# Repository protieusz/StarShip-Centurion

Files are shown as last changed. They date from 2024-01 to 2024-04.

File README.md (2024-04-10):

# StarShip-Centurion
SS Centurion a 39 keys, col staggered, 34 or 25 mm trackball keyboard

Thank you PCBWay for sponsoring my wonderful StarShip Centurion design which tooks me forever to get it right. PCBWay is your one stop PCB prototype service. Their PCBA service is top notch. Whenever you are thinking of prototype your brilliant keyboard pcbs, PCBWay is your answer.

This keyboard is inspired from Le-Chiffre and Orbital.  I never had the chance to print the Le-Chiffre pcb and always wanted one but with more features like a trackball integrated to it. The SS Centurion has more pinky stagger than the Le-Chiffre or the Orbital. The trackball location is located at the thumb area in order to make the keyboard more smaller profile and more compact. The trackball PMW3360 sensor VIK module is attached by hot glue or acrylic glue to the 3DP trackball holder from the bottom.  [PMW3360-XS VIK module](https://github.com/sadekbaroudi/vik/tree/master/pcb/pmw3360-xs) is designed by Sadek of Fingerpunch and the 3DP trackball holder is designed by @ma_po_daisuki and his designs are being sold at [his Booth store](https://ma-po.booth.pm/items/5258743) which cost around $10 cad. Go check it out and support him. The height of the trackball is adjusted using M2 standoffs and connected to the keyboard pcb by a ribbon cable to the VIK trackball module. This keyboard pcb is not VIK certified since I removed a couple of the pin connections in order to save myself the headache of routing those pin connections.  The SS Centurion also have 20 RGB lights along the cut out "slots" of the case to make it look more like a starship. No encoder was added because the QMK code allows scroll lock for the trackball and I find the scroll lock is more used than the encoder itself and save some space to make the keyboard look more compact.  The build of the SS Centurion requires a lot of DIY fixes so be warned if you decided to print is out and build your own.  It is not perfect and don't expect it to be perfect.  Print at your own risk and no support will be given. Also the 3DP trackball module screw holes are edited from the original in order to accomodate the M2 hot inserts.  There are lots of workarounds for this build.  I discovered them during building but the issues were fixed and is working.

# SS Centurion Keyboard Mat
Collaborated with Philip Lalonde (https://github.com/lalondeph/StarShip-Centurion-deskpad) to help design a keymat using SS Centurion's pcb outline and design it so that it has a FTL spaceship look.  Go check out his other keymat works as well. This guy is very talented.  The SS Centurion keymat is free for you guys to print at any shops that does custom keymat printing.  I get mine printed at [Aliexpress shop](https://www.aliexpress.com/item/1005006217695445.html?spm=a2g0o.order_list.order_list_main.22.609b1802RaJOJM). Below are some keymat pictures:





# QMK Firmware
For QMK firmware, use the Ploopy version since it has been tested and works smoothly. The code is less complicated compared to Aki27 Bally's.  I have uploaded the Aki27 but I have not tested it. It does compiles with no issue. Test at your own risk.

# Quick Video Demo Use:

https://www.instagram.com/reel/C1-lobTvvmZ/?igsh=d3Zudndwd214cmZk

# Quick RGB Demo Video:

https://youtu.be/h3FHeYk4HRs

# Final Production Pictures Jan 10, 2024:







RGB Lights - I used Costco parchment paper and glued it inside the case for the RGB slits to give it a warmer look or else super sharp and bright for the eyes.



























Trackball Setup. Janky but works.











Workaround for miscalculated USB C port opening:




Sadek VIK XS Trackball Module PCB Required:
Recommend SMD hot plate soldering. Manual hand soldering might cause you to rage quit.





For the SS Centurior build, orientate the PIN 1 to the bottom right corner. So the VIK connector will be on the other side. Another oversight. Unless you can manipulate the QMK code to have it rotate like the pic then kudos to you:



Test Fitting the Sadek's VIK XS pcb to the base of ma_po_daisuki trackball support holder





Hot Inserts DIY Fix. Insert Halfway to the side.





Switch Plate:




Pre-production Pics:

Top Case







PCB Renders

Screenshot 2023-12-02 at 3 38 40 PM
Screenshot 2023-12-02 at 3 39 11 PM
Screenshot 2023-12-02 at 3 39 32 PM


Fusion360 Renders

Screenshot 2023-11-30 at 2 51 08 AM
Screenshot 2023-11-30 at 2 46 51 AM
Screenshot 2023-11-30 at 2 46 30 AM
Screenshot 2023-11-30 at 2 46 14 AM
Screenshot 2023-11-30 at 2 46 03 AM
Screenshot 2023-11-30 at 2 45 52 AM
Screenshot 2023-11-30 at 2 44 59 AM
Screenshot 2023-11-30 at 2 45 37 AM
Screenshot 2023-11-30 at 2 43 17 AM

Mock Keycap Height Vs Trackball Reference

Screenshot 2023-11-30 at 1 59 52 AM
Screenshot 2023-11-30 at 1 57 09 AM
Screenshot 2023-11-30 at 1 56 57 AM

Pre-Chamfre Case

Screenshot_2023-11-29_at_7 44 43_PM
Screenshot_2023-11-29_at_7 44 51_PM
Screenshot_2023-11-29_at_7 44 43_PM

Sketch

Screenshot 2023-11-28 at 8 11 51 PM

KLE Mock Up

Screenshot_2023-11-28_at_12 25 36_PM

Physical Prototype Test



# License

</a></p>

You are free to:

Share — copy and redistribute the material in any medium or format

Adapt — remix, transform, and build upon the material

The licensor cannot revoke these freedoms as long as you follow the license terms.
Under the following terms:

Attribution — You must give appropriate credit, provide a link to the license, and indicate if changes were made. You may do so in any reasonable manner, but not in any way that suggests the licensor endorses you or your use.

NonCommercial — You may not use the material for commercial purposes.

ShareAlike — If you remix, transform, or build upon the material, you must distribute your contributions under the same license as the original.

No additional restrictions — You may not apply legal terms or technological measures that legally restrict others from doing anything the license permits.

StarShip Centurion by ProtieusKeebs is licensed under [CC BY-NC-SA 4.0](https://creativecommons.org/licenses/by-nc-sa/4.0/?ref=chooser-v1)

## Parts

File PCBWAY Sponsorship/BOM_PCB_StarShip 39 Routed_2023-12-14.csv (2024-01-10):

ID | Name | Designator | Footprint | Quantity | Manufacturer Part | Manufacturer | Supplier | Supplier Part | Price | link
1 | NO | GND,+3V3,CS,MISO,MOSI,SCK,+5V | PIN 1-PIN | 7
2 | TYPE-C-31-M-12 | USBC1 | USB-C_SMD-TYPE-C-31-M-12 | 1 | TYPE-C-31-M-12 | 韩国韩荣 | LCSC | C165948 | 0.159 | https://so.szlcsc.com/global.html?c=&k=C165948
3 | SK6812MINI-E_C5149201 | U13,U14,U15,U17,U25,U16,U18,U19,U20,U21,U22,U23,U24,U26,U27,U28,U29,U30,U31,U32 | LED-SMD_L3.2-W2.8-TR | 20 | SK6812MINI-E | 欧思科光电 | LCSC | C5149201 | 0.124 | https://lcsc.com/eda_search?q=C5149201&%26type=1&ref=editor
4 | SM4007PL | D205,D000,D001,D002,D003,D004,D005,D006,D007,D008,D009,D010,D105,D106,D107,D108,D109,D110,D206,D207,D208,D209,D210,D306,D307,D308,D100,D101,D102,D103,D104,D200,D201,D202,D203,D204,D302,D303,D304 | SOD-123F_L2.8-W1.8-LS3.7-RD | 39 | SM4007PL | MDD | LCSC | C64898 | 0.007 | https://item.szlcsc.com/60254.html
5 | 1uF | C1,C2,C5,C6,C9 | C0402 | 5 | CL05A105KA5NQNC | SAMSUNG(三星) | LCSC | C52923 | 0.004 | https://item.szlcsc.com/15869.html
6 | 22pF | C3,C4 | C0402 | 2 | 0402CG220J500NT | FH(风华) | LCSC | C1555 | 0.001 | https://item.szlcsc.com/15869.html
7 | 100nF | C7,C10,C11,C12,C13,C14,C15,C16 | C0402 | 8 | CL05B104KO5NNNC | SAMSUNG(三星) | LCSC | C1525 | 0.001 | https://item.szlcsc.com/15869.html
8 | 10uF | C8 | C0402 | 1 | CL05A106MQ5NUNC | SAMSUNG(三星) | LCSC | C15525 | 0.005 | https://item.szlcsc.com/15869.html
9 | PRTR5V0U2X,215 | D11 | SOT-143_L2.9-W1.3-P1.92-LS2.3-BR | 1 | PRTR5V0U2X,215 | Nexperia(安世) | LCSC | C12333 | 0.147 | https://item.szlcsc.com/280548.html
10 | BSMD0805-020-15V | F1 | F0805 | 1 | BSMD0805-020-15V | BHFUSE(佰宏) | LCSC | C883103 | 0.045 | https://item.szlcsc.com/343298.html
11 | FH12-12S-0.5SH(55) | FPC1 | FPC-SMD_FH12-12S-0.5SH-55 | 1 | FH12-12S-0.5SH(55) | HRS(广濑) | LCSC | C88360 | 0.428 | https://lcsc.com/eda_search?q=C88360&%26type=1&ref=editor
12 | 5.1kΩ | R1,R2,R3,R4,R5 | R0402 | 5 | 0402WGF5101TCE | UNI-ROYAL(厚声) | LCSC | C25905 | 0.001 | https://item.szlcsc.com/323315.html
13 | 1kΩ | R6,R7 | R0402 | 2 | 0402WGF1001TCE | UNI-ROYAL(厚声) | LCSC | C11702 | 0.001 | https://item.szlcsc.com/323315.html
14 | 27Ω | R8,R9 | R0402 | 2 | 0402WGF270JTCE | UNI-ROYAL(厚声) | LCSC | C25100 | 0.001 | https://item.szlcsc.com/323315.html
15 | RESET | U1 | RESET SWITCH | 1
16 | BOOT | U2 | RESET SWITCH | 1
17 | W25Q128JVSIQTR | U3 | SOIC-8_L5.3-W5.3-P1.27-LS8.0-BL | 1 | W25Q128JVSIQ | WINBOND(华邦) | LCSC | C97521 | 0.611 | https://item.szlcsc.com/63461.html
18 | RP2040 | U4 | LQFN-56_L7.0-W7.0-P0.4-EP | 1 | RP2040 | Raspberry Pi(树莓派) | LCSC | C2040 | 1.076 | https://atta.szlcsc.com/upload/public/pdf/source/20210621/C2040_96F425825606B7957D87DD32E2512CA9.pdf
19 | XC6206P332MR | U5 | SOT-23-3_L2.9-W1.6-P1.90-LS2.8-BR | 1 | XC6206P332MR | TOREX(特瑞仕) | LCSC | C5446 | 0.106 | https://item.szlcsc.com/14454.html
20 | SN74LVC1T45QDCKRQ1 | U6 | SC-70-6_L2.0-W1.3-P0.65-LS2.1-BR | 1 | SN74LVC1T45QDCKRQ1 | TI(德州仪器) | LCSC | C139353 | 0.382 | https://lcsc.com/eda_search?q=C139353&%26type=1&ref=editor
21 | 12MHz | X1 | OSC-SMD_4P-L3.2-W2.5-BL | 1 | X322512MSB4SI | YXC(扬兴晶振) | LCSC | C9002 | 0.059 | https://item.szlcsc.com/15866.html
22 | Switch | K205,K000,K001,K002,K003,K004,K005,K006,K007,K008,K009,K010,K105,K106,K107,K108,K109,K110,K206,K207,K208,K209,K210,K306,K307,K308,K100,K101,K102,K103,K104,K200,K201,K202,K203,K204,K302,K303,K304 | CHERRY_MX_100_MILLMAX | 39

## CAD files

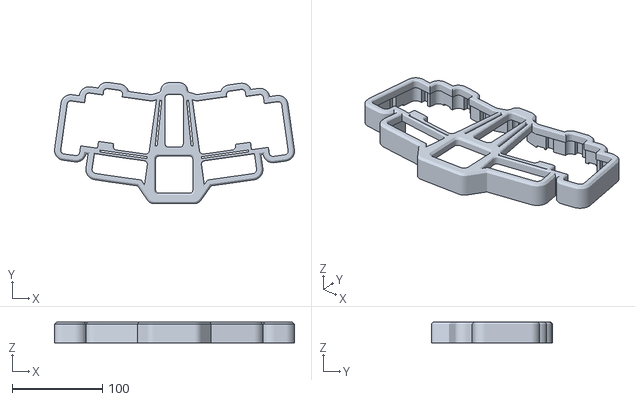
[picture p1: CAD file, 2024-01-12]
SS39TopCaseFixedUSBCPort.stl
265.6 x 134.2 x 22.8

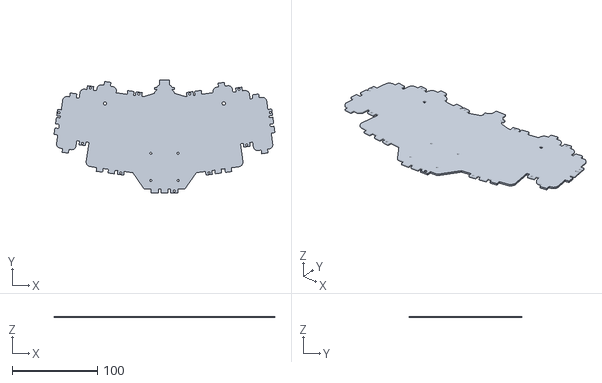
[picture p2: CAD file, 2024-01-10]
SS39BottomPlateOffsets.stl
259.1 x 132.3 x 1.60

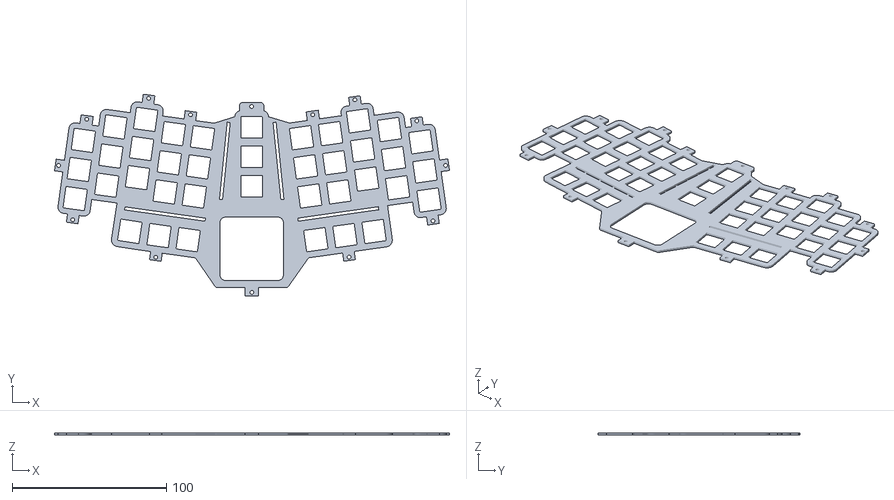
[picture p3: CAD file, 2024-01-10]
SS39SwitchPlate.stl
255.9 x 130.6 x 1.50

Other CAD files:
STEP/StarShip Centurion Top.step
STEP/StarShip Centurion Bottom.step
STEP/StarShip Centurion Switchplate.step

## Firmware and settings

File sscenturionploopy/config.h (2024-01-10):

/* Copyright 2023 Colin Lam (Ploopy Corporation)
 * Copyright 2020 Christopher Courtney, aka Drashna Jael're  (@drashna) <drashna@live.com>
 * Copyright 2019 Sunjun Kim
 *
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
 * You should have received a copy of the GNU General Public License
 * along with this program.  If not, see <http://www.gnu.org/licenses/>.
 */

#pragma once

#define RP2040_BOOTLOADER_DOUBLE_TAP_RESET // Activates the double-tap behavior
#define RP2040_BOOTLOADER_DOUBLE_TAP_RESET_TIMEOUT 200U // Timeout window in ms in which the double tap can occur.

#ifdef COMBO_ENABLE
#    define COMBO_COUNT 6
#    define COMBO_TERM 200
#endif

/* RGB LED */
//#define WS2812_PIO_USE_PIO1
#define WS2812_DI_PIN GP29

#ifdef RGBLIGHT_ENABLE
    #define RGBLED_NUM 20
    #define RGBLIGHT_LIMIT_VAL 255
    #define RGBLIGHT_HUE_STEP 10
    #define RGBLIGHT_SAT_STEP 17
    #define RGBLIGHT_VAL_STEP 17

    // #define RGBLIGHT_ANIMATIONS
    #define RGBLIGHT_EFFECT_BREATHING
    #define RGBLIGHT_EFFECT_RAINBOW_MOOD
    #define RGBLIGHT_EFFECT_RAINBOW_SWIRL
    #define RGBLIGHT_EFFECT_SNAKE
    #define RGBLIGHT_EFFECT_KNIGHT
    #define RGBLIGHT_EFFECT_CHRISTMAS
    #define RGBLIGHT_EFFECT_STATIC_GRADIENT
    #define RGBLIGHT_EFFECT_TWINKLE
    #define RGBLIGHT_EFFECT_ALTERNATING
#endif

// #define ROTATIONAL_TRANSFORM_ANGLE 0
//#define POINTING_DEVICE_INVERT_X
#define POINTING_DEVICE_INVERT_Y
//#define POINTING_DEVICE_ROTATION_180

/* PMW3360 Settings */
#define PMW33XX_LIFTOFF_DISTANCE 0x00
#define PMW33XX_CS_PIN GP17
#define SPI_SCK_PIN GP18
#define SPI_MISO_PIN GP16
#define SPI_MOSI_PIN GP19

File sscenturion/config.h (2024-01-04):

// Copyright 2023 aki27 (@aki27kbd)
// SPDX-License-Identifier: GPL-2.0-or-later

#pragma once

//#define VIAL_KEYBOARD_UID {0xC4, 0x18, 0xCC, 0x6D, 0x1C, 0x16, 0x5B, 0x8D}
//#define VIAL_UNLOCK_COMBO_ROWS {0, 0}
//#define VIAL_UNLOCK_COMBO_COLS {1, 11}

/* VIA */
//#define DYNAMIC_KEYMAP_LAYER_COUNT 8


/* key matrix size */
//#define MATRIX_COLS 13
//#define MATRIX_ROWS 4


/* tapping term */
// #define TAPPING_FORCE_HOLD
//#define TAPPING_TERM 200
// #define IGNORE_MOD_TAP_INTERRUPT

#define RP2040_BOOTLOADER_DOUBLE_TAP_RESET // Activates the double-tap behavior
#define RP2040_BOOTLOADER_DOUBLE_TAP_RESET_TIMEOUT 200U // Timeout window in ms in which the double tap can occur.

#ifdef COMBO_ENABLE
#    define COMBO_COUNT 6
#    define COMBO_TERM 200
#endif

/* Encoder */
//#define ENCODERS_PAD_A { GP11 }
//#define ENCODERS_PAD_B { GP12 }
//#define ENCODER_RESOLUTION 4

/* Matrix*/
//#define MATRIX_COL_PINS { GP25, GP24, GP23, GP22, GP21, GP26, GP27, GP20, GP19, GP18, GP17, GP16, GP13 }
//#define MATRIX_ROW_PINS { GP28, GP10, GP14, GP15 }

/* COL2ROW, ROW2COL */
//#define DIODE_DIRECTION COL2ROW


/* Set 0 if debouncing isn't needed */
//#define DEBOUNCE 5


/* Mechanical locking support. Use KC_LCAP, KC_LNUM or KC_LSCR instead in keymap (Very Important for Scroll Lock!!!) */
#undef LOCKING_SUPPORT_ENABLE
/* Locking resynchronize hack */
#undef LOCKING_RESYNC_ENABLE


/* RGB LED */
//#define WS2812_PIO_USE_PIO1
#define WS2812_DI_PIN GP29

#ifdef RGBLIGHT_ENABLE
    #define RGBLED_NUM 20
    #define RGBLIGHT_LIMIT_VAL 255
    #define RGBLIGHT_HUE_STEP 10
    #define RGBLIGHT_SAT_STEP 17
    #define RGBLIGHT_VAL_STEP 17

    // #define RGBLIGHT_ANIMATIONS
    #define RGBLIGHT_EFFECT_BREATHING
    #define RGBLIGHT_EFFECT_RAINBOW_MOOD
    #define RGBLIGHT_EFFECT_RAINBOW_SWIRL
    #define RGBLIGHT_EFFECT_SNAKE
    #define RGBLIGHT_EFFECT_KNIGHT
    #define RGBLIGHT_EFFECT_CHRISTMAS
    #define RGBLIGHT_EFFECT_STATIC_GRADIENT
    #define RGBLIGHT_EFFECT_TWINKLE
    #define RGBLIGHT_EFFECT_ALTERNATING
#endif


/* Trackball */

#ifdef POINTING_DEVICE_ENABLE

//#    undef RP_SPI_USE_SPI0
//#    define RP_SPI_USE_SPI0 TRUE
//#    undef RP_SPI_USE_SPI1
//#    define RP_SPI_USE_SPI1 FALSE
#    define SPI_DRIVER SPID0

//#    define SPI_SCK_PIN GP22 //6
//#    define SPI_MISO_PIN GP24 //4
//#    define SPI_MOSI_PIN GP23 //7
#    define SPI_SCK_PIN GP18
#    define SPI_MISO_PIN GP16
#    define SPI_MOSI_PIN GP19

#endif


#ifndef PMW33XX_CS_PIN
#    define PMW33XX_CS_PIN GP17
#endif
#define POINTING_DEVICE_INVERT_X
#define POINTING_DEVICE_INVERT_Y
//#define ROTATIONAL_TRANSFORM_ANGLE 90
#define POINTING_DEVICE_ROTATION_180

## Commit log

2024-01-10 Updated the orientation and mouse buttons.
    Use this. The Latest QMK firmware.
2024-01-10 Production Files
    [BOM_PCB_StarShip 39 Routed_2023-12-14.csv, PickAndPlace_PCB_StarShip 39 Routed_2023-12-14.csv]
2024-01-10 Case, switch plate, bottom case
    [SS39BottomPlateOffsets.stl, SS39SwitchPlate.stl, SS39TopCase.stl]
2024-01-12 Use this TOP case Instead.
    [SS39TopCaseFixedUSBCPort.stl]
2024-04-11 STEP files for case and switch plate
    [StarShip Centurion Bottom.step, StarShip Centurion Switchplate.step, StarShip Centurion Top.step]

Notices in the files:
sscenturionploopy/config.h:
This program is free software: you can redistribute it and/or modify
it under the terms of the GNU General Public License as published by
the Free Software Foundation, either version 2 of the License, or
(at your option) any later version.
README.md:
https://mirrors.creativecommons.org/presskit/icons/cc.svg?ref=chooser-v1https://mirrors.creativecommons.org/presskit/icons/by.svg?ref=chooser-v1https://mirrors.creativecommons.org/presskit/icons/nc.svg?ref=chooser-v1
